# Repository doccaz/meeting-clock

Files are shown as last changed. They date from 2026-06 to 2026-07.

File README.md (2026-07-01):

# Meeting Clock

A desk-mounted meeting monitor built from 8× MAX7219 8×8 LED matrices (2 rows of 4),
running on a Raspberry Pi Pico or **Pico W**. Features countdown/stopwatch timers,
a scrolling message board with multiple effects, an OLED + rotary encoder +
2-button control panel, a passive buzzer, and a rechargeable LiPo battery with
USB-C charging.

WiFi, MQTT (Home Assistant), and the web UI are **auto-detected** at boot —
a plain Pico runs fully offline with no config change needed.

## Repo structure

- **`wiring/`** — parts list and full wiring diagram (pin assignments, power
  architecture, battery voltage-sense divider).
- **`firmware/`** — MicroPython firmware. See `firmware/README.md` for setup
  instructions and board compatibility table.
- **`case/`** — parametric OpenSCAD 3D-printable case (fused front housing +
  removable back panel) plus ready-to-slice STLs and preview renders.

## Quick start

1. Read `wiring/meeting-monitor-wiring-and-parts.md` and build the hardware.
2. Flash MicroPython onto the Pico (or Pico W), then follow `firmware/README.md`.
3. Print `case/front_housing.stl` and `case/back_panel.stl`.
4. **Pico W only:** on first boot connect to the `MeetingMonitor-Setup` WiFi AP
   to configure WiFi + MQTT via the on-device web UI at `http://192.168.4.1`.
   Plain Pico boots straight into offline mode — no setup needed.

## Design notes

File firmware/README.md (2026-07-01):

# Meeting Monitor — Firmware (MicroPython)

Compatible with both **Raspberry Pi Pico** and **Pico W**.
WiFi, MQTT, and the web UI are auto-detected at boot: on a plain Pico they
are silently disabled and the device runs fully offline. No config change
needed — just flash and go.

## Files
- `main.py` — entry point; auto-detects WiFi and assembles the task list
- `config.py` — pin map and defaults (edit if your wiring differs)
- `display.py` / `max7219.py` — drives the two 4×MAX7219 chains, scroll/blink effects
- `timers.py` — countdown / stopwatch logic
- `buzzer.py` — passive buzzer tones/alerts
- `ui.py` — encoder + 2 buttons + OLED menu; WiFi-only settings shown greyed out on plain Pico
- `mqtt_handler.py` — Home Assistant MQTT integration (Pico W only)
- `webserver.py` — WiFi STA/AP manager + settings/control web UI (Pico W only)

## Board compatibility

| Feature | Pico | Pico W |
|---|---|---|
| Timers, display, effects | ✅ | ✅ |
| Encoder / buttons / OLED | ✅ | ✅ |
| Buzzer | ✅ | ✅ |
| Battery monitoring | ✅ | ✅ |
| WiFi / AP setup web UI | — | ✅ |
| MQTT (Home Assistant) | — | ✅ |

## One-time setup

1. Flash the official **Raspberry Pi Pico / Pico W MicroPython firmware**.
   Use the Pico W build if you want WiFi (it includes the `network` module);
   use the standard Pico build for offline-only use.
2. Install dependencies (only needed on Pico W, or if you have WiFi):
   ```python
   import mip
   mip.install("ssd1306")
   mip.install("umqtt.simple")
   ```
   On a plain Pico, only `ssd1306` is needed and can be installed the same way
   or copied manually from micropython-lib.
3. Copy all `.py` files to the Pico's root (e.g. via Thonny "Save As →
   Raspberry Pi Pico", or `mpremote cp *.py :`).
4. Reset the board.
   - **Pico W (first boot, no saved credentials):** starts AP mode — connect
     to `MeetingMonitor-Setup` (password `configure123`), browse to
     `http://192.168.4.1`, enter WiFi + MQTT details, save.
   - **Plain Pico:** boots straight into offline mode, no setup needed.

## OLED settings menu (plain Pico)

WiFi-dependent items (AP Mode, MQTT Reconnect, WiFi Reset) appear with a
`-` prefix and cannot be selected — they are visible but inactive, so the
menu layout stays consistent regardless of board.

## Scroll effects (message scroller)
- `static` — text held in place
- `scroll_left` — classic marquee
- `scroll_up` — vertical scroll
- `blink` — flashing text

Set via the OLED menu, or on Pico W via the web UI / MQTT.

## MQTT (Pico W / Home Assistant)
Default topic prefix: `meetingmonitor` (change in `config.py`).
- Subscribe `meetingmonitor/cmd` — send JSON commands:
  ```json
  {"action": "countdown", "seconds": 300}
  {"action": "message", "text": "In a meeting", "effect": "scroll_left"}
  {"action": "brightness", "level": 5}
  ```
- Publishes `meetingmonitor/status` (retained) every 15 s with current
  mode/timer/battery state — usable as an HA MQTT sensor.

## Battery monitoring
A voltage divider (2×100kΩ) taps the raw LiPo+ terminal (before the boost
converter) into GP26/ADC0 — see `../wiring/` for the full diagram.

## Related
- `../case/` — 3D-printable case (fused front housing + removable back panel), STLs and OpenSCAD source.
- `../wiring/` — full parts list and wiring diagram.

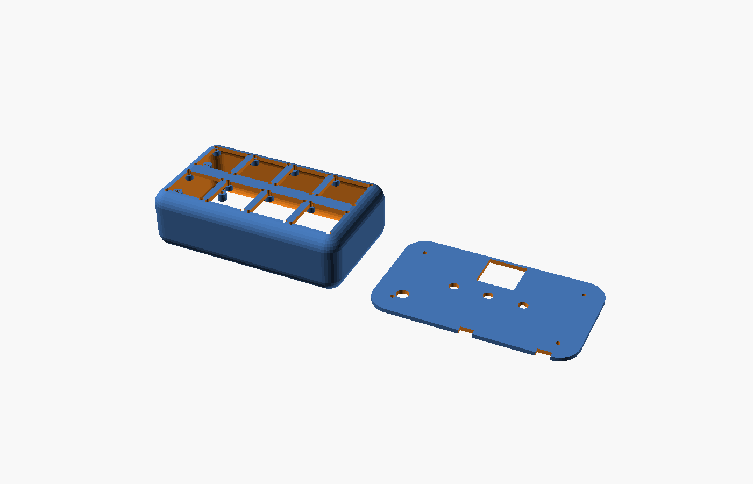
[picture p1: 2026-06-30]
case/preview_layout.png

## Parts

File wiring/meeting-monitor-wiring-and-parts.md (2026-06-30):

# Meeting Monitor — Parts List & Wiring Plan

## Parts List

| Component | Qty | Notes |
|---|---|---|
| Raspberry Pi Pico W | 1 | MicroPython firmware |
| MAX7219 FC-16 8x8 LED matrix module | 8 | 2 chains of 4, daisy-chained |
| 0.96" I2C OLED (SSD1306) | 1 | 128x64 |
| EC11 rotary encoder w/ push switch | 1 | Nav + select |
| Tactile push button | 2 | Start/Pause, Back/Reset |
| Passive piezo buzzer | 1 | PWM-driven |
| TP4056 USB-C LiPo charger board | 1 | On hand |
| LiPo battery, 2000mAh+ (1S, 3.7V) | 1 | JST connector |
| Boost converter module (5V, 1.5A+ output, e.g. MT3608) | 1 | LiPo (3.7-4.2V) → stable 5V for Pico VSYS + matrices |
| Slide switch (power on/off) | 1 | Between battery/charger and boost converter |
| Jumper wire / ribbon cable | — | For SPI chains |
| Perfboard or custom PCB | 1 | Optional, for clean wiring |
| 10kΩ resistors | 2 | Pull-ups for buttons if not using internal pull-ups (optional) |
| 100kΩ resistors | 2 | Battery voltage-sense divider (see below) |

**Note:** I added a boost converter to the list. The TP4056 outputs raw LiPo voltage (3.0–4.2V), which is NOT enough to reliably run 8 MAX7219 modules (they want 5V) or power Pico's VSYS pin cleanly. The boost converter sits between the battery/TP4056 and everything else.

---

## Power Architecture

```
[LiPo Battery] ──┬── [TP4056 charge IN/OUT] ── (charges battery via USB-C)
                  │
                  └── [Slide Switch] ── [Boost Converter 5V] ──┬── Pico W (VSYS, pin 39)
                                                                ├── MAX7219 chain 1 (VCC)
                                                                ├── MAX7219 chain 2 (VCC)
                                                                ├── OLED (VCC, via Pico 3V3 actually — see below)
                                                                └── Buzzer (via GPIO, not direct power)
```

- OLED runs on 3.3V — power it from the **Pico's 3V3 OUT pin**, not the 5V rail.
- Buzzer and encoder/buttons are logic-level — powered/driven via GPIO, not the 5V rail.
- Common ground across battery, boost converter, Pico, and all matrices — this is critical, don't skip it.

---

## SPI Chains (2x4 matrices each)

Pico W has two hardware SPI peripherals (SPI0, SPI1) — perfect for 2 independent chains.

| Chain | SPI Bus | Pico Pins (SCK / MOSI / CS) | Matrices |
|---|---|---|---|
| Row 1 (top) | SPI0 | GP18 (SCK) / GP19 (MOSI) / GP17 (CS) | 4x FC-16 daisy-chained |
| Row 2 (bottom) | SPI1 | GP10 (SCK) / GP11 (MOSI) / GP13 (CS) | 4x FC-16 daisy-chained |

Within each chain: module 1's "OUT" header connects to module 2's "IN" header, etc. Only the first module in each chain connects to the Pico's SCK/MOSI/CS; power (5V/GND) should be injected at both ends of each chain of 4 if possible to avoid voltage droop across the row.

---

## OLED (I2C)

| Pico Pin | OLED Pin |
|---|---|
| GP0 | SDA |
| GP1 | SCL |
| 3V3 OUT | VCC |
| GND | GND |

---

## Encoder (EC11)

| Pico Pin | Encoder Pin |
|---|---|
| GP2 | A |
| GP3 | B |
| GP4 | Push switch |
| GND | GND/COM |

Use internal pull-ups in software (`Pin.PULL_UP`) — no external resistors needed.

---

## Buttons

| Pico Pin | Button |
|---|---|
| GP5 | Button A (Start/Pause) |
| GP6 | Button B (Back/Reset) |

Both wired to GND with internal pull-ups enabled in software.

---

## Buzzer

| Pico Pin | Buzzer |
|---|---|
| GP7 | Signal (PWM) |
| GND | GND |

---

## Pin Budget Check

Used: GP0,1 (OLED), GP2,3,4 (encoder), GP5,6 (buttons), GP7 (buzzer), GP10,11,13 (SPI1), GP17,18,19 (SPI0) = 14 GPIO pins used. Pico W has 26 usable GPIO — plenty of headroom left for future additions (e.g. a light sensor, second buzzer, status LED).

---

## Battery Voltage Sense (for OLED % display)

Tap raw LiPo+ (before the boost converter, directly off the battery/TP4056 B+ terminal) with a 100k/100k divider into GP26 (ADC0):

```
LiPo+ ──[100kΩ]──┬──[100kΩ]── GND
                  │
                 GP26 (ADC0)
```

This halves the battery voltage (4.2V → 2.1V) so it stays safely under the Pico's 3.3V ADC max. Keep this tap separate from the 5V boost rail — it must read the raw cell voltage, not the regulated output.

---

## Open Items / Decisions Needed (resolved)

1. **Matrix brightness** — defaults to ~30% software brightness (level 3/15), adjustable via webUI/MQTT/encoder.
2. **Enclosure** — built as two printed parts: a single fused front housing (side walls + front face with all 8 module windows/standoffs printed as one continuous shell, no seam) and a removable back panel (OLED, encoder, buttons, buzzer, USB-C, power switch). See `../case/` for STLs and source.

All open items resolved — see `../case/` and `../firmware/` for the finished design.

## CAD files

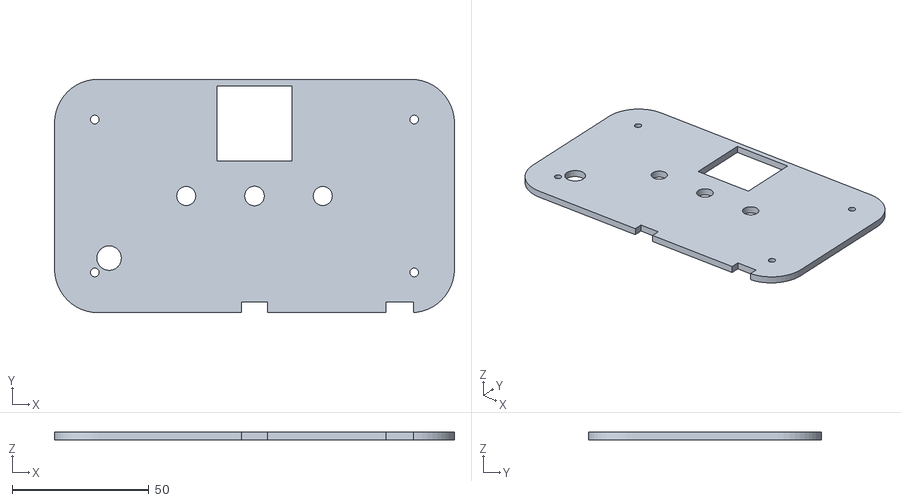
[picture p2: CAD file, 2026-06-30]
case/back_panel.stl
146.5 x 85.5 x 3.00

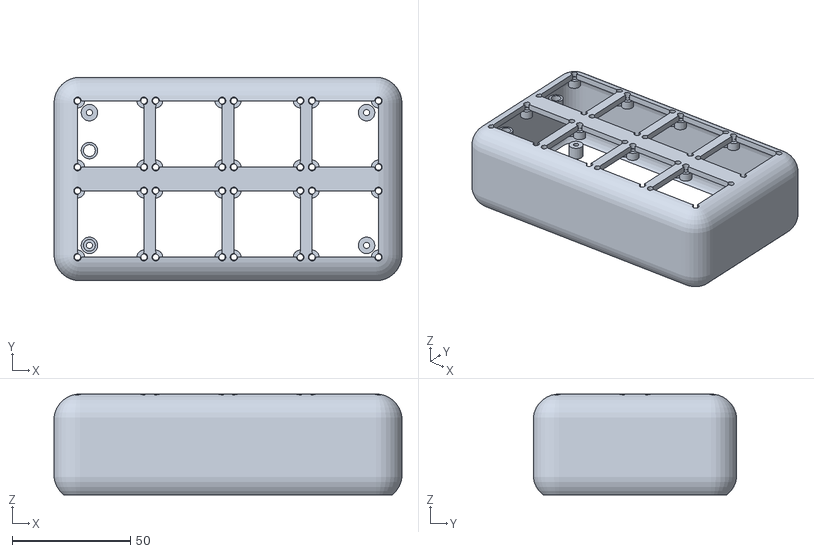
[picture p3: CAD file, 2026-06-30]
case/front_housing.stl
146.9 x 85.9 x 42.6

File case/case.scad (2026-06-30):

// =====================================================================
// Meeting Monitor - 3D Printable Case (parametric, OpenSCAD)
// Desk-stand style, two parts:
//   1) front_housing - front face (2x4 module windows) FUSED with the
//      side/top/bottom walls as a single continuous shell (no seam)
//   2) back_panel - removable lid: OLED, encoder, buttons, buzzer,
//      USB-C, power switch
// =====================================================================
// PRINT NOTE: FC-16 mounting-hole positions vary slightly between
// manufacturers. Verify hole_inset against your actual boards before
// printing - adjust the single variable below if needed.

// ---------- Module / array dimensions ----------
module_size      = 32;     // FC-16 PCB is ~32x32mm
module_gap_x     = 1;      // gap between modules within a row (chained, tight)
row_gap_y        = 6;      // gap between row 1 and row 2 (visual separation)
cols             = 4;
rows             = 2;

array_w = cols * module_size + (cols - 1) * module_gap_x;   // ~131mm
array_h = rows * module_size + row_gap_y;                    // ~70mm

// FC-16 mounting holes: 4 corners, inset from PCB edge (adjust if your
// boards differ - common value is ~2mm inset, M2.5/M3 clearance hole)
hole_inset   = 2;
hole_dia     = 3.2;   // M3 clearance

// LED viewing window per module (slightly smaller than PCB so the wall
// overlaps mounting tabs / solder points at the edge)
window_margin = 2;
window_w = module_size - 2 * window_margin;
window_h = module_size - 2 * window_margin;

// ---------- Housing dimensions ----------
plate_thickness   = 3;        // front-face / back-panel wall thickness
frame_border      = 8;        // border around the array on the front face
faceplate_w = array_w + 2 * frame_border;
faceplate_h = array_h + 2 * frame_border;

tilt_angle   = 20;            // desk-stand tilt, degrees back from vertical

cavity_depth      = 42;       // usable internal depth for Pico W, battery, boost, wiring
total_depth = cavity_depth + plate_thickness;  // overall housing depth incl. front face
wall_thickness    = 2.4;      // side/top/bottom wall thickness

// ---------- Back panel cutouts ----------
oled_w = 27.5;  oled_h = 27.5;       // 0.96" OLED active/board cutout window
encoder_hole_dia = 7.2;              // EC11 shaft clearance
btn_hole_dia = 7;
buzzer_hole_dia = 9;
usb_c_w = 9.5; usb_c_h = 4;
power_switch_w = 10; power_switch_h = 5;

// ---------- Rounding / organic shaping ----------
plate_corner_r   = 16;   // corner fillet on the back panel footprint
enclosure_edge_r = 11;   // fillet radius on all 12 edges of the housing shell
leg_round_r      = 9;    // roundness of the stand-leg gussets
back_lip_clearance = 0.25; // printable clearance between back panel and housing opening

// rounded rectangle (2D)
module rounded_rect(w, h, r) {
    hull() {
        for (cx = [r, w - r]) {
            for (cy = [r, h - r]) {
                translate([cx, cy]) circle(r = r, $fn = 48);
            }
        }
    }
}

module rounded_plate(w, h, th, r) {
    linear_extrude(height = th) rounded_rect(w, h, r);
}

// fully rounded box (all 12 edges filleted), outer bounding box = [w,h,d]
module rounded_box(w, h, d, r) {
    hull() {
        for (cx = [r, w - r]) {
            for (cy = [r, h - r]) {
                for (cz = [r, d - r]) {
                    translate([cx, cy, cz]) sphere(r = r, $fn = 32);
                }
            }
        }
    }
}

module boss(screw_r) {
    difference() {
        cylinder(d=7, h=6, $fn=24);
        cylinder(d=screw_r*2, h=7, $fn=24);
    }
}

// =====================================================================
// FRONT HOUSING - single fused shell: side/top/bottom walls + front
// face with module windows, all printed as one part (no seam).
// z=0 is the open BACK (back_panel attaches here); z=total_depth is
// the FRONT outer face where the 8 matrices mount.
// =====================================================================
module front_housing() {
    outer_w = faceplate_w;
    outer_h = faceplate_h;

    difference() {
        rounded_box(outer_w, outer_h, total_depth, enclosure_edge_r);

        // hollow out everything except the side walls + the front face
        // slab (thickness = plate_thickness). Cavity is inset by
        // wall_thickness in x/y, and open past the back (z<=0) so the
        // back stays fully accessible.
        translate([wall_thickness, wall_thickness, -1])
            rounded_box(outer_w - 2*wall_thickness, outer_h - 2*wall_thickness,
                        cavity_depth + 1, max(1, enclosure_edge_r - wall_thickness));

        // 8 viewing windows + 32 mounting holes, cut straight through
        // the integrated front face
        for (r = [0:rows-1]) {
            for (c = [0:cols-1]) {
                x = frame_border + c * (module_size + module_gap_x);
                y = frame_border + r * (module_size + row_gap_y);

                translate([x + window_margin, y + window_margin, total_depth - plate_thickness - 1])
                    linear_extrude(height = plate_thickness + 2)
                        rounded_rect(window_w, window_h, 2.5);

                for (hx = [hole_inset, module_size - hole_inset]) {
                    for (hy = [hole_inset, module_size - hole_inset]) {
                        translate([x + hx, y + hy, total_depth - plate_thickness - 1])
                            cylinder(d=hole_dia, h=plate_thickness + 2, $fn=24);
                    }
                }
            }
        }
    }

    // module mounting standoffs, printed on the INSIDE of the front
    // face, protruding back into the cavity
    for (r = [0:rows-1]) {
        for (c = [0:cols-1]) {
            x = frame_border + c * (module_size + module_gap_x);
            y = frame_border + r * (module_size + row_gap_y);
            for (hx = [hole_inset, module_size - hole_inset]) {
                for (hy = [hole_inset, module_size - hole_inset]) {
                    translate([x + hx, y + hy, total_depth - plate_thickness])
                        rotate([180,0,0])
                            difference() {
                                cylinder(d=6, h=4, $fn=24);
                                translate([0,0,-0.5]) cylinder(d=2.6, h=5, $fn=24); // pilot hole
                            }
                }
            }
        }
    }

    // internal mounting bosses for Pico W (approx 21x51mm board),
    // protruding from the inside of the front face into the cavity
    translate([15, 15, total_depth - plate_thickness])
        rotate([180,0,0]) boss(2.5);
    translate([15, 55, total_depth - plate_thickness])
        rotate([180,0,0]) boss(2.5);

    // 4 corner standoff posts near the open back rim, for back_panel
    // screws (back_panel becomes a removable lid)
    for (cx = [enclosure_edge_r + 4, outer_w - enclosure_edge_r - 4]) {
        for (cy = [enclosure_edge_r + 4, outer_h - enclosure_edge_r - 4]) {
            translate([cx, cy, wall_thickness])
                difference() {
                    cylinder(d=7, h=6, $fn=24);
                    cylinder(d=2.6, h=7, $fn=24); // self-tap pilot for M3
                }
        }
    }
}

// =====================================================================
// BACK PANEL (removable lid: OLED window, encoder, 2 buttons, buzzer
// hole, USB-C cutout, power switch cutout, + 4 screw clearance holes
// matching the standoff posts in front_housing)
// =====================================================================
module back_panel() {
    outer_w = faceplate_w;
    outer_h = faceplate_h;
    panel_w = outer_w - 2*back_lip_clearance;
    panel_h = outer_h - 2*back_lip_clearance;

    difference() {
        rounded_plate(panel_w, panel_h, plate_thickness, plate_corner_r);

        // OLED window, upper-center
        translate([panel_w/2 - oled_w/2, panel_h - 30, -1])
            cube([oled_w, oled_h, plate_thickness + 2]);

        // encoder, center
        translate([panel_w/2, panel_h/2, -1])
            cylinder(d=encoder_hole_dia, h=plate_thickness + 2, $fn=32);

        // two buttons either side of encoder
        translate([panel_w/2 - 25, panel_h/2, -1])
            cylinder(d=btn_hole_dia, h=plate_thickness + 2, $fn=24);
        translate([panel_w/2 + 25, panel_h/2, -1])
            cylinder(d=btn_hole_dia, h=plate_thickness + 2, $fn=24);

        // buzzer hole, lower-left
        translate([20, 20, -1])
            cylinder(d=buzzer_hole_dia, h=plate_thickness + 2, $fn=24);

        // USB-C charge port, bottom edge center
        translate([panel_w/2 - usb_c_w/2, -1, plate_thickness/2 - usb_c_h/2])
            cube([usb_c_w, plate_thickness + 2, usb_c_h]);

        // power slide switch, bottom-right
        translate([panel_w - 25, -1, plate_thickness/2 - power_switch_h/2])
            cube([power_switch_w, plate_thickness + 2, power_switch_h]);
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

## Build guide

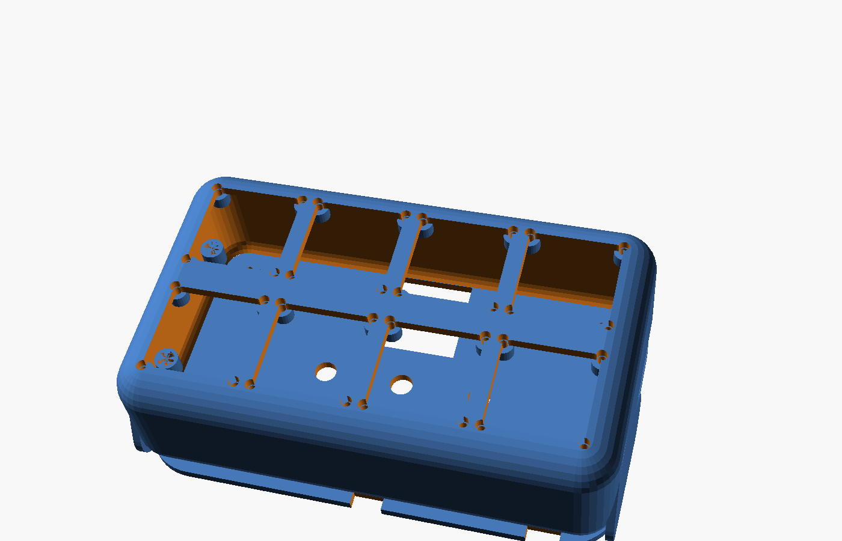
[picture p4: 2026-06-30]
case/preview_assembled.png

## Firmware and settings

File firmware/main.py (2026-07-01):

"""
main.py - entry point.

Auto-detects WiFi capability at boot by trying to import `network`.
On a plain Pico (no wireless), WiFi / MQTT / web server are skipped
entirely and the app runs fully offline. On a Pico W they boot normally.
"""
import uasyncio as asyncio
import time
from machine import ADC, Pin

import config
from display import Display, Zone
from timers import Timer
from buzzer import Buzzer
from ui import UI

# ---- WiFi capability auto-detect ----
try:
    import network as _net  # noqa: F401  (just testing import)
    WIFI_CAPABLE = True
except ImportError:
    WIFI_CAPABLE = False

if WIFI_CAPABLE:
    import webserver
    import mqtt_handler

DEFAULT_MESSAGES = [
    "Meeting in progress",
    "Please knock",
    "Back in 5 minutes",
    "Welcome!",
]

# Battery monitoring: resistor divider from the RAW LiPo+ terminal (before
# the boost converter) into GP26 (ADC0), per the wiring doc — 100k/100k
# halves 4.2V down to 2.1V, safely under the 3.3V ADC max.
BATTERY_ADC_PIN = 26
BATTERY_DIVIDER_RATIO = 2.0
BATTERY_MIN_V = 3.3
BATTERY_MAX_V = 4.2


class _NullWifi:
    """Drop-in stub so App code never needs to branch on WIFI_CAPABLE."""
    mode = "none"
    def status_string(self): return "No WiFi"
    def try_connect_sta(self, *a, **kw): return False
    def start_ap(self): pass


class _NullMqtt:
    connected = False
    def connect(self): pass
    def poll(self): pass
    def publish_status(self): pass


class App:
    def __init__(self):
        self.wifi_capable = WIFI_CAPABLE
        self.display = Display()
        self.buzzer = Buzzer(config.BUZZER_PIN)
        self.timer = Timer("countdown")
        self.timer.on_done = self._on_timer_done
        self.mode = None
        self.saved_messages = list(DEFAULT_MESSAGES)
        self.current_message = None
        self._pending_wifi_reconnect = False
        self._pending_mqtt_reconnect = False

        if WIFI_CAPABLE:
            settings = webserver.load_settings()
            self.wifi = webserver.WifiManager()
            self.mqtt = mqtt_handler.MqttHandler(
                self,
                broker=settings.get("mqtt_broker", config.MQTT_BROKER),
                port=settings.get("mqtt_port", config.MQTT_PORT),
                client_id=config.MQTT_CLIENT_ID,
                prefix=config.MQTT_TOPIC_PREFIX,
                user=settings.get("mqtt_user", config.MQTT_USER),
                password=settings.get("mqtt_pass", config.MQTT_PASS),
            )
        else:
            settings = {}
            self.wifi = _NullWifi()
            self.mqtt = _NullMqtt()

        self.brightness_level = settings.get("brightness", config.DEFAULT_BRIGHTNESS)
        self.display.brightness(self.brightness_level)

        try:
            self.battery_adc = ADC(Pin(BATTERY_ADC_PIN))
        except Exception:
            self.battery_adc = None

        self.ui = UI(self)

    # ---- boot sequence ----
    def boot_network(self):
        if not WIFI_CAPABLE:
            return
        settings = webserver.load_settings()
        ssid = settings.get("wifi_ssid", config.WIFI_SSID)
        password = settings.get("wifi_pass", config.WIFI_PASS)
        if not self.wifi.try_connect_sta(ssid, password):
            self.wifi.start_ap()

    # ---- timer actions ----
    def start_countdown(self, seconds):
        self.mode = "countdown"
        self.timer = Timer("countdown")
        self.timer.on_done = self._on_timer_done
        self.timer.set_duration(seconds)
        self.timer.start()
        self.display.row2.set_text("", Zone.EFFECT_STATIC)

    def start_stopwatch(self):
        self.mode = "stopwatch"
        self.timer = Timer("stopwatch")
        self.timer.on_done = self._on_timer_done
        self.timer.start()
        self.display.row2.set_text("", Zone.EFFECT_STATIC)

    def toggle_timer(self):
        self.timer.toggle()

    def reset_timer(self):
        self.timer.reset()

    def stop_timer(self):
        self.timer.reset()
        self.mode = None

    def _on_timer_done(self):
        self.buzzer.alert_done()

    def show_message(self, text, effect="scroll_left"):
        self.mode = "message"
        self.current_message = text
        self.display.row1.set_text(text, effect, speed_ms=60)

    def clear_display(self):
        self.display.clear()
        self.mode = None

    # ---- settings actions ----
    def cycle_brightness(self):
        self.brightness_level = (self.brightness_level + 3) % 16
        self.set_brightness(self.brightness_level)

    def set_brightness(self, level):
        self.brightness_level = level
        self.display.brightness(level)
        if WIFI_CAPABLE:
            s = webserver.load_settings()
            s["brightness"] = level
            webserver.save_settings(s)

    def toggle_ap_mode(self):
        if not WIFI_CAPABLE:
            return
        if self.wifi.mode == "ap":
            self._pending_wifi_reconnect = True
        else:
            self.wifi.start_ap()

    def reconnect_mqtt(self):
        if WIFI_CAPABLE:
            self._pending_mqtt_reconnect = True

    def reset_wifi_settings(self):
        if not WIFI_CAPABLE:
            return
        s = webserver.load_settings()
        s["wifi_ssid"] = ""
        s["wifi_pass"] = ""
        webserver.save_settings(s)
        self.wifi.start_ap()

    def request_wifi_reconnect(self):
        self._pending_wifi_reconnect = True

    def request_mqtt_reconnect(self):
        self._pending_mqtt_reconnect = True

    # ---- remote (MQTT) command handling ----
    def handle_remote_command(self, cmd):
        action = cmd.get("action")
        if action == "countdown":
            self.start_countdown(int(cmd.get("seconds", 300)))
        elif action == "stopwatch_start":
            self.start_stopwatch()
        elif action == "timer_pause":
            self.timer.pause()
        elif action == "timer_resume":
            self.timer.start()
        elif action == "timer_reset":
            self.reset_timer()
        elif action == "message":
            self.show_message(cmd.get("text", ""), cmd.get("effect", "scroll_left"))
        elif action == "brightness":
            self.set_brightness(int(cmd.get("level", config.DEFAULT_BRIGHTNESS)))
        elif action == "clear":
            self.clear_display()

    def state_dict(self):
        return {
            "mode": self.mode,
            "timer_state": self.timer.state,
            "timer_display": self.timer.display_string(),
            "brightness": self.brightness_level,
            "wifi": self.wifi.status_string(),
            "battery_pct": self.battery_percent(),
        }

    # ---- status/info helpers for UI ----
    def clock_string(self):
        t = time.localtime()
        return "{:02d}:{:02d}:{:02d}".format(t[3], t[4], t[5])

    def wifi_status_string(self):
        return self.wifi.status_string()

    def mqtt_status_string(self):
        return "OK" if self.mqtt.connected else "--"

    def active_mode_label(self):
        return {"countdown": "Countdown", "stopwatch": "Stopwatch",
                "message": "Message"}.get(self.mode, "Idle")

    def battery_percent(self):
        if not self.battery_adc:
            return -1
        raw = self.battery_adc.read_u16()
        v_adc = (raw / 65535) * 3.3
        v_batt = v_adc * BATTERY_DIVIDER_RATIO
        pct = (v_batt - BATTERY_MIN_V) / (BATTERY_MAX_V - BATTERY_MIN_V) * 100
        return max(0, min(100, round(pct)))


# ---- async tasks ----

async def task_display_tick(app):
    while True:
        app.display.tick()
        await asyncio.sleep_ms(20)


async def task_timer_tick(app):
    while True:
        app.timer.tick()
        if app.mode in ("countdown", "stopwatch"):
            app.display.row1.set_text(app.timer.display_string(), Zone.EFFECT_STATIC)
        await asyncio.sleep_ms(200)


async def task_ui_poll(app):
    while True:
        app.ui.update()
        await asyncio.sleep_ms(15)


async def task_mqtt_poll(app):
    while True:
        if app._pending_mqtt_reconnect:
            app._pending_mqtt_reconnect = False
            app.mqtt.connected = False
            app.mqtt.connect()
        app.mqtt.poll()
        await asyncio.sleep_ms(100)


async def task_mqtt_status_publish(app):
    while True:
        app.mqtt.publish_status()
        await asyncio.sleep(15)


async def task_wifi_watchdog(app):
    while True:
        if app._pending_wifi_reconnect:
            app._pending_wifi_reconnect = False
            settings = webserver.load_settings()
            ssid = settings.get("wifi_ssid", config.WIFI_SSID)
            password = settings.get("wifi_pass", config.WIFI_PASS)
            if not app.wifi.try_connect_sta(ssid, password):
                app.wifi.start_ap()
        await asyncio.sleep(2)


async def main():
    app = App()
    app.boot_network()

    tasks = [
        task_display_tick(app),
        task_timer_tick(app),
        task_ui_poll(app),
    ]

    if WIFI_CAPABLE:
        await webserver.run_server(app, port=80)
        app.mqtt.connect()
        tasks += [
            task_mqtt_poll(app),
            task_mqtt_status_publish(app),
            task_wifi_watchdog(app),
        ]

    await asyncio.gather(*tasks)


if __name__ == "__main__":
    asyncio.run(main())

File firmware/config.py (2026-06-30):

"""
config.py - central pin map and settings. Edit WIFI/MQTT here or via the web UI
(web UI writes to settings.json which overrides these defaults at boot).
"""

# ---- SPI chains for matrices ----
SPI0_ID = 0
SPI0_SCK = 18
SPI0_MOSI = 19
SPI0_CS = 17
ROW1_MODULES = 4  # top row

SPI1_ID = 1
SPI1_SCK = 10
SPI1_MOSI = 11
SPI1_CS = 13
ROW2_MODULES = 4  # bottom row

DEFAULT_BRIGHTNESS = 3  # 0-15, ~30% per project notes (≈3-4/15)

# ---- OLED (I2C) ----
OLED_SDA = 0
OLED_SCL = 1
OLED_I2C_ID = 0
OLED_WIDTH = 128
OLED_HEIGHT = 64
OLED_ADDR = 0x3C

# ---- Encoder ----
ENC_A = 2
ENC_B = 3
ENC_SW = 4

# ---- Buttons ----
BTN_A = 5  # Start/Pause
BTN_B = 6  # Back/Reset

# ---- Buzzer ----
BUZZER_PIN = 7

# ---- Wifi / MQTT defaults (overridden by settings.json if present) ----
WIFI_SSID = ""
WIFI_PASS = ""
AP_SSID = "MeetingMonitor-Setup"
AP_PASS = "configure123"

MQTT_BROKER = ""
MQTT_PORT = 1883
MQTT_USER = ""
MQTT_PASS = ""
MQTT_CLIENT_ID = "meeting-monitor"
MQTT_TOPIC_PREFIX = "meetingmonitor"
# Subscribes:  meetingmonitor/cmd          (JSON commands)
# Publishes:   meetingmonitor/status       (JSON state, retained)

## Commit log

2026-06-30 Initial commit: wiring diagram, MicroPython firmware, 3D-printable case
    [back_panel.stl, case.scad, front_housing.stl]
2026-06-30 Docs: fix stale case-design references (fused front housing, not separate front/rear panels)
2026-07-01 feat: Pico/Pico W compatibility — WiFi/MQTT/webUI auto-detected, greyed-out settings on plain Pico
